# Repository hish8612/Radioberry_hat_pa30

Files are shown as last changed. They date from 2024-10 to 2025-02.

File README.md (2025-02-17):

# [Radioberry_hat_pa30](https://github.com/hish8612/Radioberry_hat_pa30)

beta0.2 Release

This project provides a preamplifier to drive a [30W-PA (HL2-PA30 by ji1udd)](https://github.com/ji1udd/HL2-PA30) for Radioberry-2. It will be plugged on top of the radioberry-2.<br>

#### Feature
・Preamplifire(OPA2674) based on [radioberry.hat](https://github.com/pa3gsb/Radioberry-2.x/tree/master/hardware/hat)<br>
・On board ADC(MAX11613) for measuring pa-current, temperature and pa-fwd/rev from HL2-PA30 board. <br>
・Paddle or straight key inputs and PTT(Key) inputs.<br>
・No-latency sidetone output at [local CW operation.](https://github.com/hish8612/Hermes-Lite2/tree/master/gateware/variants/radioberry_cl025_cwsidetone)<br>

#### Board View

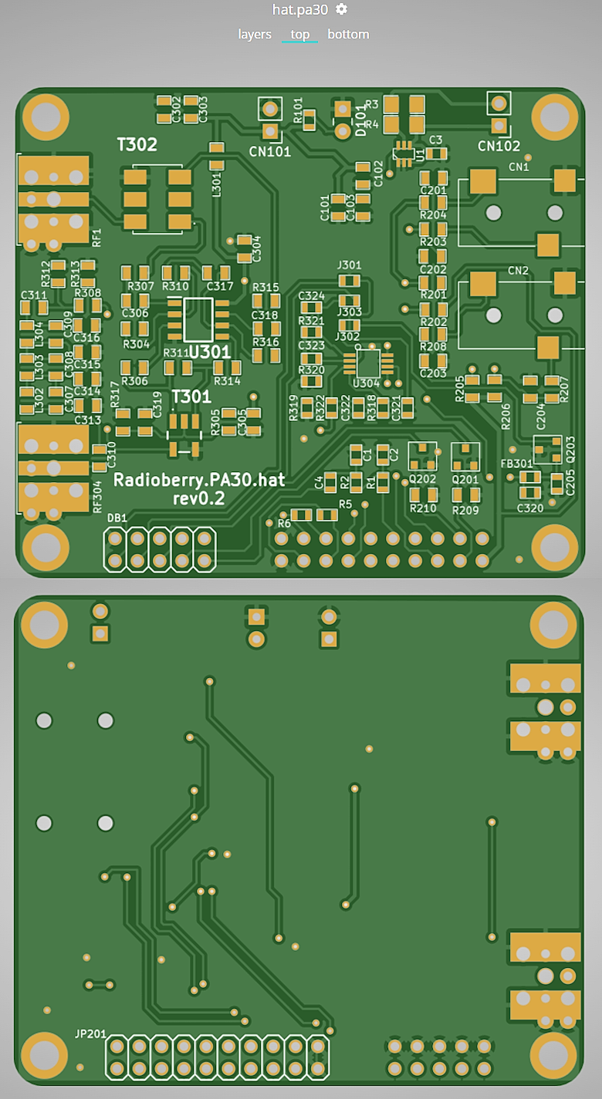
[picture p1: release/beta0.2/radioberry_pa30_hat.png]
<br>

#### Connection diagram (beta0.1)

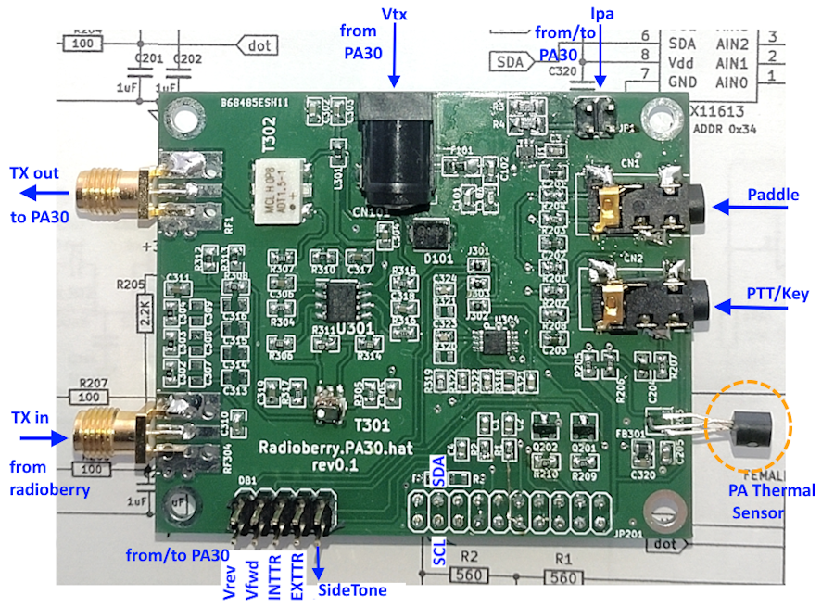
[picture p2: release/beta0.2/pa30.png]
<br>

#### HL2-PA30 modifications.

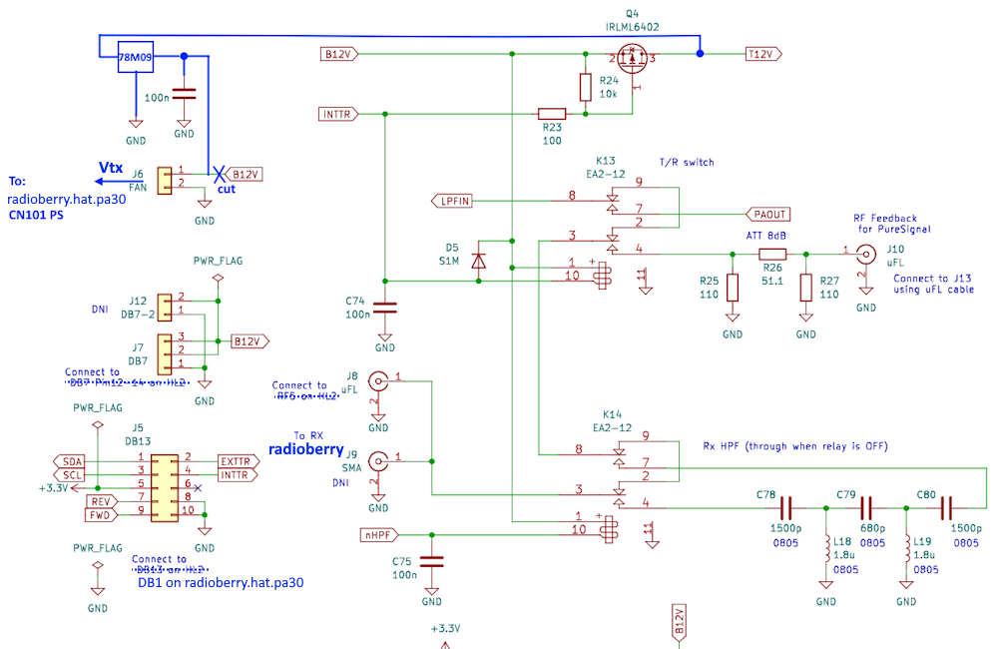
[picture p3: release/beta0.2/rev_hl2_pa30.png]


#### PA30 mesurements.

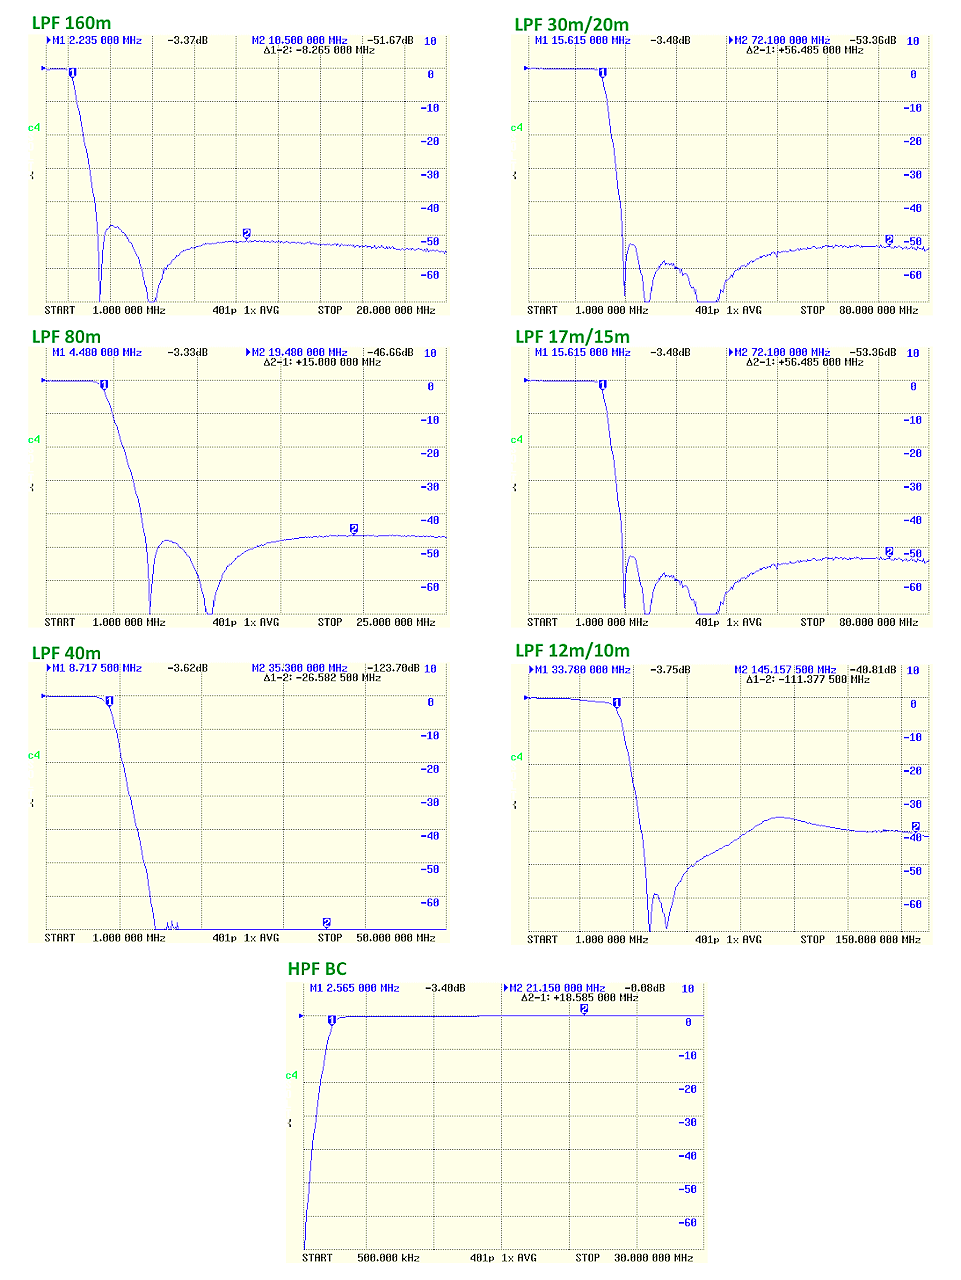
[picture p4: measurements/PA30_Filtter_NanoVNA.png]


// end item

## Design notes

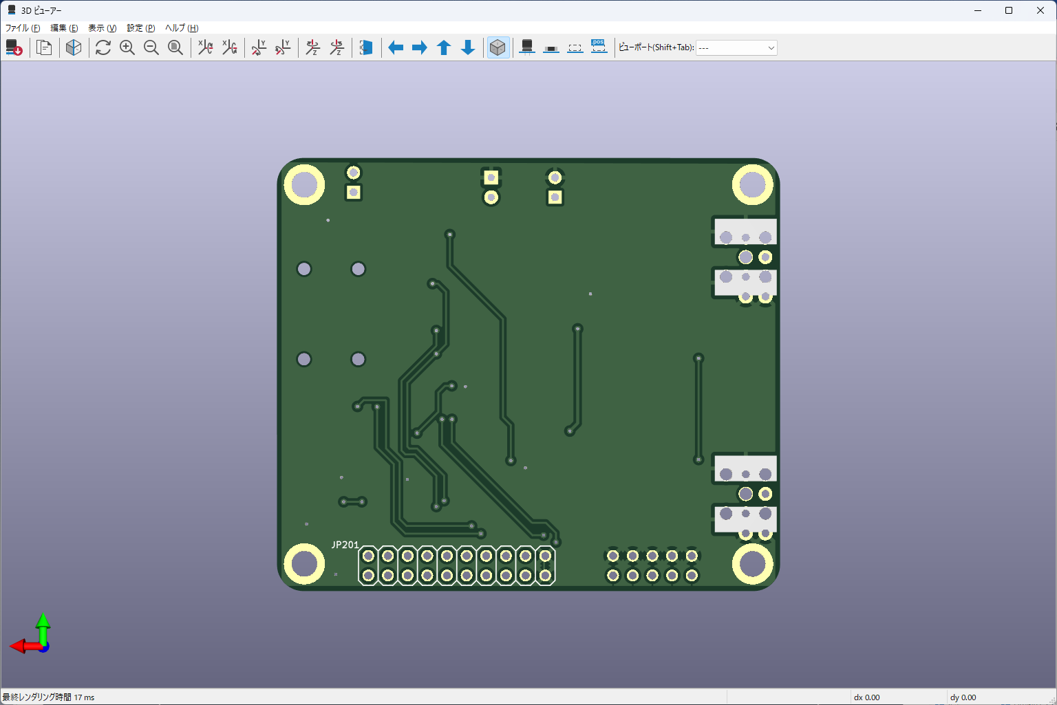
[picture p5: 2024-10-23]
bmp/BottomView.png

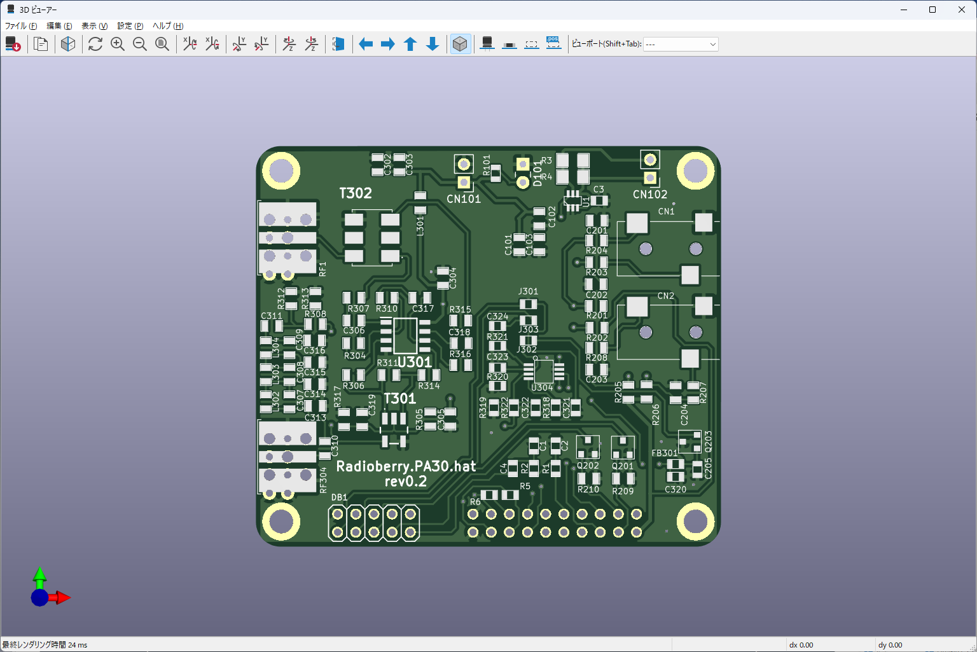
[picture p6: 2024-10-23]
bmp/TopView.png

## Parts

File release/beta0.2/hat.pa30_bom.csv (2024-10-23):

Source: | D:\KiCad\hat_pa30_r0.2\hat.pa30.kicad_sch
Date: | 2024/10/23 16:53:36
Tool: | Eeschema 7.0.8
Generator: | D:\Program\KiCad7.0.8\bin\scripting\plugins/bom_csv_grouped_by_value.py
Component Count: | 98
Collated Components:
Item | Qty | Reference(s) | Value | LibPart | Footprint | Datasheet | DNP | Category | DK_Datasheet_Link | DK_Detail_Page | Description | Digi-Key_PN | Family | Height | Key | MPN | Manufacturer | Manufacturer_Name | Manufacturer_Part_Number | Mouser Part Number | Mouser Price/Stock | Option | Option | Status
1 | 3 | C1, C2, C4 | 104 | Device:C | HERMESLITE:SMD-0603 | ~
2 | 3 | C3, C205, C320 | 0.1uF | hermeslite:C_Small | HERMESLITE:SMD-0603
3 | 1 | C101 | 10pF | hermeslite:C_Small | HERMESLITE:SMD-0805
4 | 2 | C102, C315 | 100pF | hermeslite:C_Small | HERMESLITE:SMD-0805
5 | 1 | C103 | 10uF | hermeslite:C_Small | HERMESLITE:SMD-0805
6 | 4 | C201, C202, C203, C204 | 1uF | hermeslite:C_Small | HERMESLITE:SMD-0805
7 | 10 | C302, C303, C304, C305, C306, C310, C311, C317, C318, C319 | 0.1uF | hermeslite:C_Small | HERMESLITE:SMD-0805
8 | 1 | C307 | 5.6pF | hermeslite:C_Small | HERMESLITE:SMD-0805
9 | 1 | C308 | 30pF | hermeslite:C_Small | HERMESLITE:SMD-0805
10 | 1 | C309 | 20pF | hermeslite:C_Small | HERMESLITE:SMD-0805
11 | 1 | C313 | 82pF | hermeslite:C_Small | HERMESLITE:SMD-0805
12 | 1 | C314 | 110pF | hermeslite:C_Small | HERMESLITE:SMD-0805
13 | 1 | C316 | 68pF | hermeslite:C_Small | HERMESLITE:SMD-0805
14 | 4 | C321, C322, C323, C324 | 4.7nF | hermeslite:C_Small | HERMESLITE:SMD-0603 |  |  |  |  |  |  |  |  |  |  |  |  |  |  |  |  | DNI
15 | 2 | CN1, CN2 | SJ-3523-SMT-TR | Radioberry_LPF:SJ-3523-SMT-TR | HERMESLITE:CWJACK2 | https://www.cui.com/product/resource/digikeypdf/sj-352x-smt_series.pdf |  | Connectors, Interconnects | https://www.cui.com/product/resource/digikeypdf/sj-352x-smt_series.pdf | /product-detail/en/cui-inc/SJ-3523-SMT-TR/CP-3523SJCT-ND/669704 | CONN JACK STEREO 3.5MM SMD R/A | CP-3523SJCT-ND | Barrel - Audio Connectors |  |  | SJ-3523-SMT-TR | CUI Inc. |  |  |  |  |  |  | Active
16 | 2 | CN101, CN102 | PS | hermeslite:CONN_01X02 | Connector_PinHeader_2.54mm:PinHeader_1x02_P2.54mm_Vertical
17 | 1 | D101 | LED | Device:LED | LED_THT:LED_Rectangular_W3.0mm_H2.0mm | ~
18 | 1 | DB1 | IO10 | hermeslite:IO10 | RB:PINHEAD_2X5
19 | 1 | FB301 | FB | hermeslite:FB | HERMESLITE:SMD-0603
20 | 3 | J301, J302, J303 | JNC | hermeslite:JNC | HERMESLITE:SMD-0603
21 | 1 | JP201 | FEMALE_PINHEAD_PINHD-2X10 | Radioberry:PINHEAD_PINHD-2X10 | RB:PINHEAD_2X10
22 | 1 | L301 | L_Small | hermeslite:L_Small | HERMESLITE:SMD-0805
23 | 1 | L302 | 160nH | hermeslite:L_Small | HERMESLITE:SMD-0805
24 | 2 | L303, L304 | 130nH | hermeslite:L_Small | HERMESLITE:SMD-0805
25 | 4 | MH1, MH2, MH3, MH4 | DNI | hermeslite:TEST_1P | HERMESLITE:m3 |  |  |  |  |  |  |  |  |  | NOBOM |  |  |  |  |  |  | DNI | DNI
26 | 2 | Q201, Q202 | NUD3124 | hermeslite:MOSFET_N | HERMESLITE:SOT23_3
27 | 1 | Q203 | MCP9700 | hermeslite:MCP9700 | HERMESLITE:SOT23_3
28 | 2 | R1, R2 | 560 | Device:R | HERMESLITE:SMD-0603 | ~
29 | 2 | R3, R4 | 0.04 | hermeslite:R | HERMESLITE:SMD-1206
30 | 2 | R5, R6 | 0 | Device:R | HERMESLITE:SMD-0603 | ~
31 | 1 | R101 | 1.8k | Device:R | HERMESLITE:SMD-0603 | ~
32 | 4 | R201, R202, R205, R206 | 2.2K | hermeslite:R | HERMESLITE:SMD-0805
33 | 4 | R203, R204, R207, R208 | 100 | hermeslite:R | HERMESLITE:SMD-0805
34 | 2 | R209, R210 | 4.7K | hermeslite:R | HERMESLITE:SMD-0805
35 | 2 | R304, R316 | 510 | hermeslite:R | HERMESLITE:SMD-0805
36 | 2 | R305, R317 | 1K | hermeslite:R | HERMESLITE:SMD-0805
37 | 2 | R306, R314 | 12 | hermeslite:R | HERMESLITE:SMD-0805
38 | 2 | R307, R315 | 4R99 | hermeslite:R | HERMESLITE:SMD-0805
39 | 3 | R308, R312, R313 | 0 | hermeslite:R | HERMESLITE:SMD-0805 |  |  |  |  |  |  |  |  |  |  |  |  |  |  |  |  | DNI
40 | 1 | R310 | 300 | hermeslite:R | HERMESLITE:SMD-0805
41 | 1 | R311 | 200 | hermeslite:R | HERMESLITE:SMD-0805
42 | 4 | R318, R319, R320, R321 | 1K | hermeslite:R | HERMESLITE:SMD-0603 |  |  |  |  |  |  |  |  |  |  |  |  |  |  |  |  | DNI
43 | 1 | R322 | 270 | hermeslite:R | HERMESLITE:SMD-0603
44 | 2 | RF1, RF304 | SMA | hermeslite:BNC | HERMESLITE:SMAEDGE_THFULL_L
45 | 1 | T301 | TC4-1T | hermeslite:TRANSF4CT | tc4-1t:TC41T
46 | 1 | T302 | ADT1.5-1+ | ADT1.5-1+:ADT1.5-1+ | ADT1.5-1+:ADT151 | https://www.minicircuits.com/pdfs/ADT1.5-1.pdf |  |  |  |  | Audio Transformers / Signal Transformers RF XFMR / SURF MOUNT / RoHS 50 0.5 to 650 MHz |  |  | 2.84 |  |  |  | Mini-Circuits | ADT1.5-1+ | 139-ADT1.5-1 | https://www.mouser.co.uk/ProductDetail/Mini-Circuits/ADT1.5-1%2b?qs=xZ%2FP%252Ba9zWqaiA7HsYCvAPA%3D%3D
47 | 1 | U1 | INA199A1DC | hermeslite:INA199x1 | HERMESLITE:PE4259
48 | 1 | U301 | OPA2674 | hermeslite:LM358 | OPA2674:SOIC127P600X175-8N | ns/lm158.pdf
49 | 1 | U304 | MAX11613 | hermeslite:MAX11613 | HERMESLITE:MAX11613 | DOCUMENTATION

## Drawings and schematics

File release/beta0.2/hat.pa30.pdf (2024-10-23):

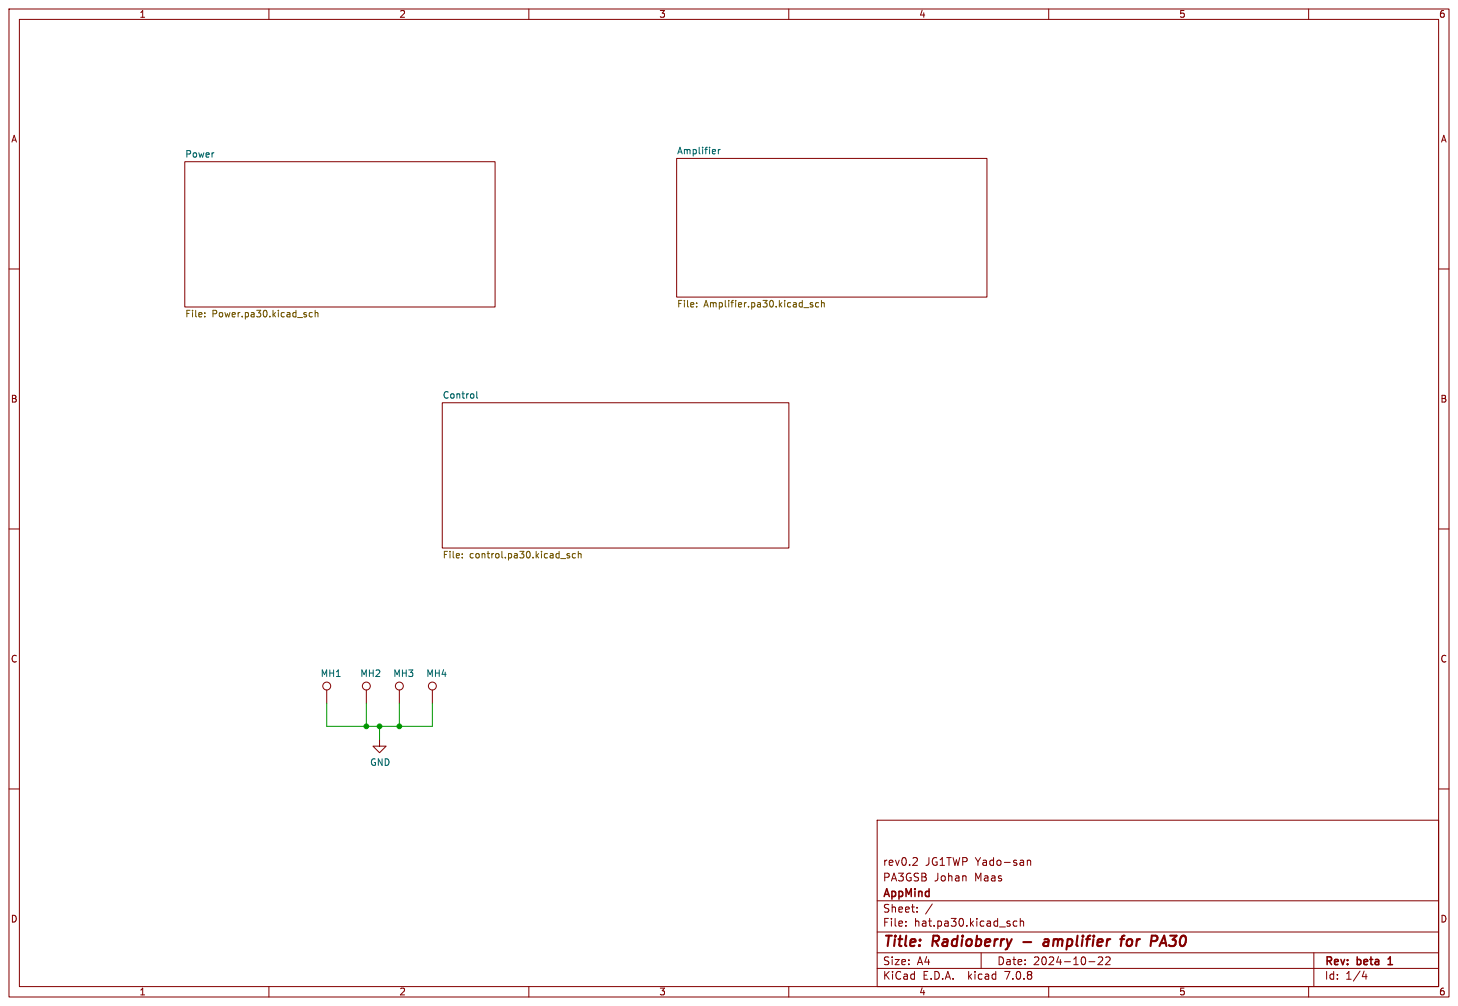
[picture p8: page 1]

Id: 1/4 Title: Radioberry - amplifier for PA30

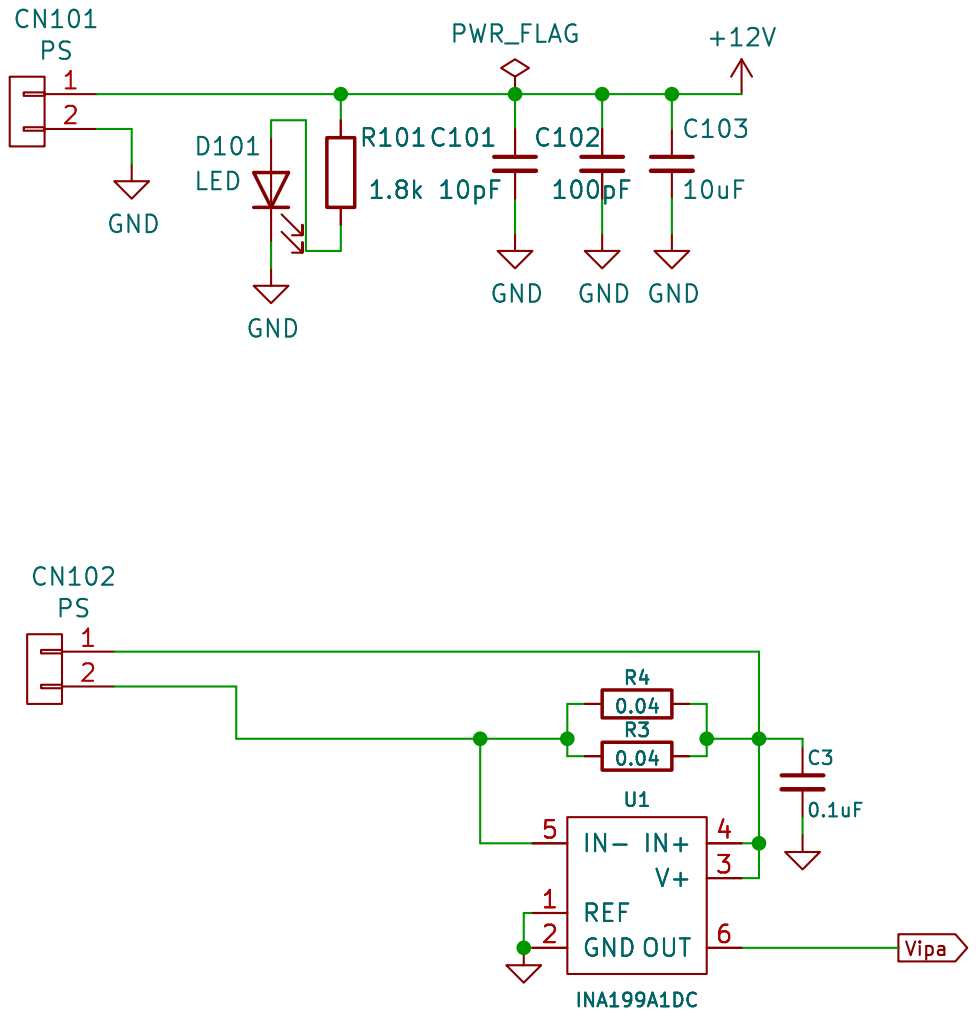
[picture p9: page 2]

Id: 2/4 Title: Radioberry - amplifier for PA30

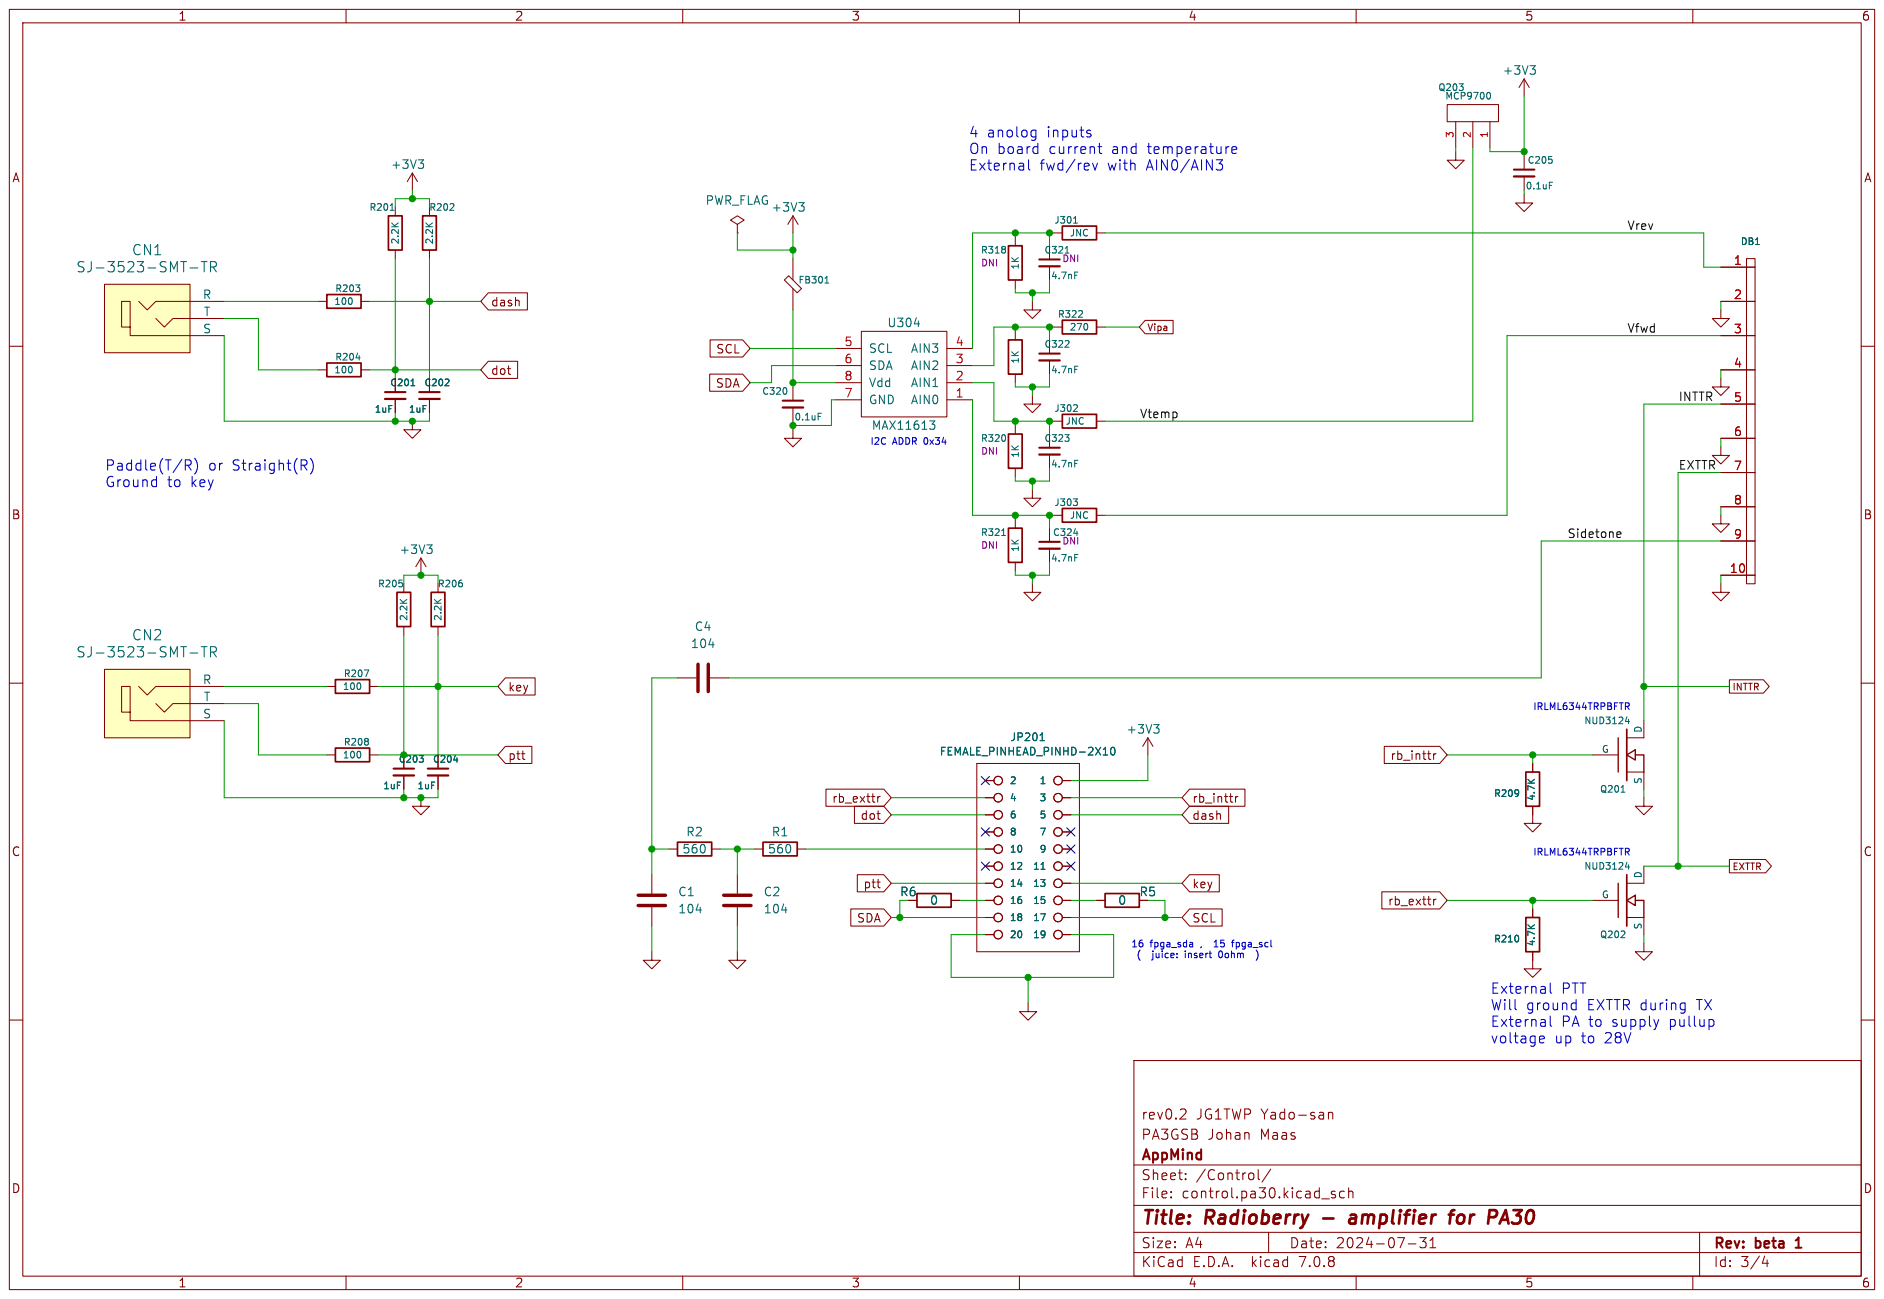
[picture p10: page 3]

External PA to supply pullup
voltage up to 28V

Id: 3/4 Title: Radioberry - amplifier for PA30

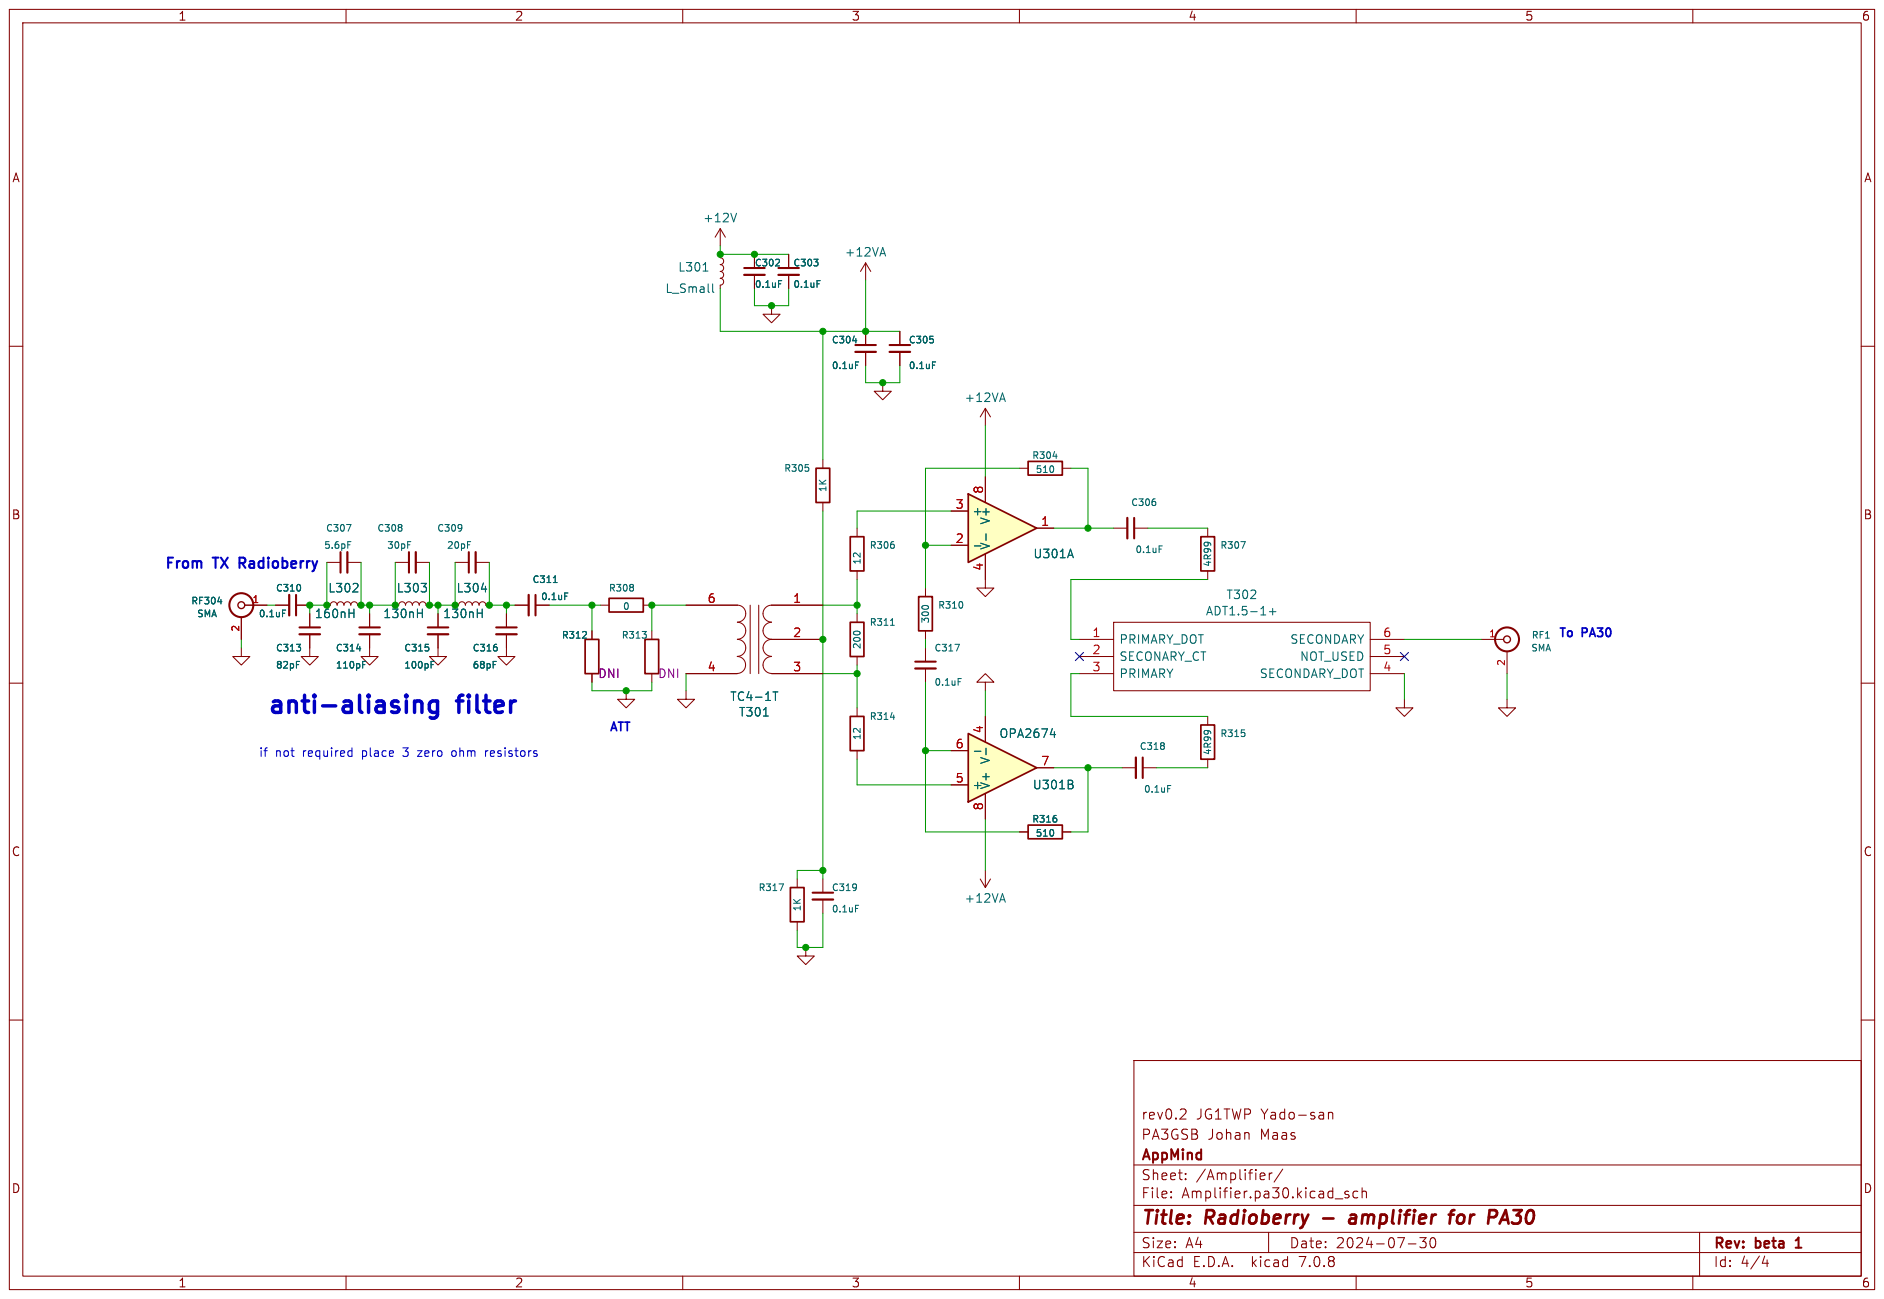
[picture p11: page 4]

File: Amplifier.pa30.kicad_sch Sheet: /Amplifier/
Id: 4/4 Title: Radioberry - amplifier for PA30

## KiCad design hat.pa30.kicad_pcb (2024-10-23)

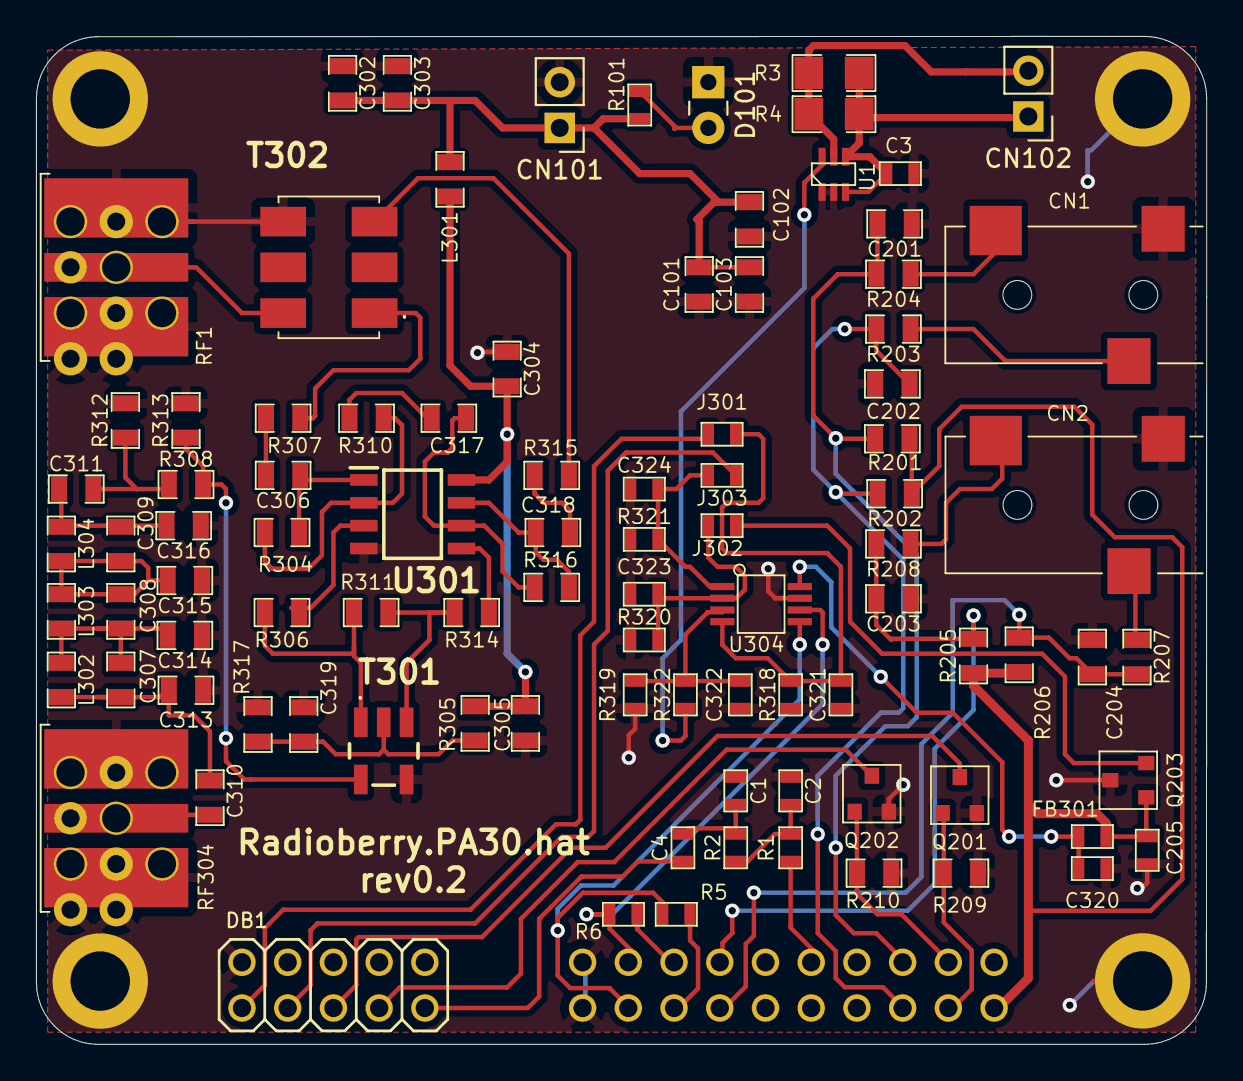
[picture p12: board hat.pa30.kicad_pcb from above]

Board: 2 copper layers, 65.0 x 56.0 mm, 98 parts (1 on the bottom side), 58 nets.

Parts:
C1, C2, C4: 104; SMD-0603
C3, C205, C320: 0.1uF; SMD-0603
C101: 10pF; SMD-0805
C102, C315: 100pF; SMD-0805
C103: 10uF; SMD-0805
C201, C202, C203, C204: 1uF; SMD-0805
C302, C303, C304, C305, C306, C310, C311, C317, C318, C319: 0.1uF; SMD-0805
C307: 5.6pF; SMD-0805
C308: 30pF; SMD-0805
C309: 20pF; SMD-0805
C313: 82pF; SMD-0805
C314: 110pF; SMD-0805
C316: 68pF; SMD-0805
C321, C322, C323, C324: 4.7nF; SMD-0603
CN1, CN2: SJ-3523-SMT-TR; CWJACK2
CN101, CN102: PS; PinHeader_1x02_P2.54mm_Vertical
D101: LED; LED_Rectangular_W3.0mm_H2.0mm
DB1: IO10; PINHEAD_2X5
FB301: FB; SMD-0603
J301, J302, J303: JNC; SMD-0603
JP201: FEMALE_PINHEAD_PINHD-2X10; PINHEAD_2X10
L301: L_Small; SMD-0805
L302: 160nH; SMD-0805
L303, L304: 130nH; SMD-0805
MH1, MH2, MH3, MH4: DNI; m3
Q201, Q202: NUD3124; SOT23_3
Q203: MCP9700; SOT23_3
R1, R2: 560; SMD-0603
R3, R4: 0.04; SMD-1206
R5, R6: 0; SMD-0603
R101: 1.8k; SMD-0603
R201, R202, R205, R206: 2.2K; SMD-0805
R203, R204, R207, R208: 100; SMD-0805
R209, R210: 4.7K; SMD-0805
R304, R316: 510; SMD-0805
R305, R317: 1K; SMD-0805
R306, R314: 12; SMD-0805
R307, R315: 4R99; SMD-0805
R308, R312, R313: 0; SMD-0805
R310: 300; SMD-0805
R311: 200; SMD-0805
R318, R319, R320, R321: 1K; SMD-0603
R322: 270; SMD-0603
RF1, RF304: SMA; SMAEDGE_THFULL_L
T301: TC4-1T; TC41T
T302: ADT1.5-1+; ADT151
U1: INA199A1DC; PE4259
U301: OPA2674; SOIC127P600X175-8N
U304: MAX11613

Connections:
+3V3: C205.1, FB301.1, JP201.1, Q203.1, R201.2, R202.2, R205.2, R206.2
+12V: C101.1, C102.1, C103.1, C302.1, C303.1, CN101.1, L301.1, R101.1
+12VA: C304.1, C305.1, L301.2, R305.2, U301.8 (V+)
/Control/Sidetone: C4.2, DB1.9
/Control/Vfwd: DB1.3, J303.2
/Control/Vrev: DB1.1, J301.2
/Control/Vtemp: J302.2, Q203.2
EXTTR: DB1.7, Q202.3 (D)
GND: C1.2, C2.2, C3.2, C101.2, C102.2, C103.2, C201.2, C202.2, C203.2, C204.2, C205.2, C302.2, C303.2, C304.2, C305.2, C313.2, C314.2, C315.2, C316.2, C319.2, C320.2, C321.2, C322.2, C323.2, C324.2, CN1.1 (S), CN2.1 (S), CN101.2, D101.1 (K), DB1.2, DB1.4, DB1.6, DB1.8, DB1.10, JP201.19, JP201.20, MH1.1, MH2.1, MH3.1, MH4.1, Q201.2 (S), Q202.2 (S), Q203.3, R209.1, R210.1, R312.1, R313.1, R317.1, R318.1, R319.1, R320.1, R321.1, RF1.2 (Ext), RF304.2 (Ext), T301.4 (S2), T302.4 (SECONDARY_DOT), U1.1 (REF), U1.2 (GND), U301.4 (V-), U304.7 (GND)
INTTR: DB1.5, Q201.3 (D)
unnamed: C1.1, C4.1, R2.1
unnamed: C2.1, R1.1, R2.2
unnamed: C306.1, R307.1
unnamed: C306.2, R304.1, U301.1
unnamed: C307.1, C310.1, C313.1, L302.1
unnamed: C307.2, C308.1, C314.1, L302.2, L303.1
unnamed: C308.2, C309.1, C315.1, L303.2, L304.1
unnamed: C309.2, C311.2, C316.1, L304.2
unnamed: C311.1, R308.2, R312.2
unnamed: C317.1, R310.2
unnamed: C318.1, R315.2
unnamed: C318.2, R316.1, U301.7
unnamed: CN1.3 (R), R203.2
unnamed: CN1.2 (T), R204.2
unnamed: CN2.3 (R), R207.2
unnamed: CN2.2 (T), R208.2
unnamed: C3.1, CN102.1, R3.1, R4.1, U1.3 (V+), U1.4 (IN+)
unnamed: CN102.2, R3.2, R4.2, U1.5 (IN-)
unnamed: D101.2 (A), R101.2
unnamed: JP201.10, R1.2
unnamed: JP201.15, R5.1
unnamed: JP201.16, R6.2
unnamed: RF1.1 (In), T302.6 (SECONDARY)
unnamed: C310.2, RF304.1 (In)
unnamed: C319.1, R305.1, R317.2, T301.2 (PM)
unnamed: R306.2, R311.1, T301.1 (PR1)
unnamed: R311.2, R314.1, T301.3 (PR2)
unnamed: R308.1, R313.2, T301.6 (S1)
unnamed: R315.1, T302.3 (PRIMARY)
unnamed: R307.2, T302.1 (PRIMARY_DOT)
unnamed: R306.1, U301.3 (+)
unnamed: R304.2, R310.1, U301.2 (-)
unnamed: R314.2, U301.5 (+)
unnamed: C317.2, R316.2, U301.6 (-)
unnamed: C324.1, J303.1, R321.2, U304.1 (AIN0)
unnamed: C323.1, J302.1, R320.2, U304.2 (AIN1)
unnamed: C322.1, R319.2, R322.1, U304.3 (AIN2)
unnamed: C321.1, J301.1, R318.2, U304.4 (AIN3)
unnamed: C320.1, FB301.2, U304.8 (Vdd)
SCL: JP201.17, R5.2, U304.5 (SCL)
SDA: JP201.18, R6.1, U304.6 (SDA)
Vipa: R322.2, U1.6 (OUT)
dash: C202.1, JP201.5, R202.1, R203.1
dot: C201.1, JP201.6, R201.1, R204.1
key: C204.1, JP201.13, R206.1, R207.1
ptt: C203.1, JP201.14, R205.1, R208.1
rb_exttr: JP201.4, Q202.1 (G), R210.2
rb_inttr: JP201.3, Q201.1 (G), R209.2

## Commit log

2024-10-23 1st release (beta0.2)
    [hat.pa30-B_Cu.gbl, hat.pa30-B_Mask.gbs, hat.pa30-B_Silkscreen.gbo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]
2025-02-17 Added PA30 filter characteristics
